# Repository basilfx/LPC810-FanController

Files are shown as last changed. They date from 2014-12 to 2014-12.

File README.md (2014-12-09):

# LPC810 Fan Controller
Tiny PID-based fan controller board and firmware, to insert between 3-pin fans.

## Contents
* Eagle schematic and PCB
* Firmware
* PID simulator and monitor

## Eagle

### Bill of Materials
The value of is a pullup resistor for the DS18B20 temperature sensor. While 4.7k is adviced, I use 470 in parasite mode. Higher values did not work for higher temperatures.

| Part | Value  | Device | Package |
|---|---|---|---|
| R1 | 470 | R-EU_R0603 | R0603 |
| R2 | 10k | R-EU_R0603 | R0603 |
| R3 | 10k | R-EU_R0603 | R0603 |
| R4 | 10k | R-EU_R0603 | R0603 |
| C1 | 100nF  | C-EUC0603 | C0603 |
| C2 | 2.2µF  | C-EUC0805 | C0805 |
| C3 | 100nF  | C-EUC0603 | C0603 |
| C4 | 2.2µF  | C-EUC0805 | C0805 |
| Q1 | BSH103 | MOSFET-NCHANNEL | SOT23 |
| U1 | LP2985 | LP2985-33DBVT | SOT95P  |
| U2 | LPC810 | LPC810M021FN8 | DIP8 |

### Board render
The board measures 0.45x0.95 inch. Below a render of the top and bottom.

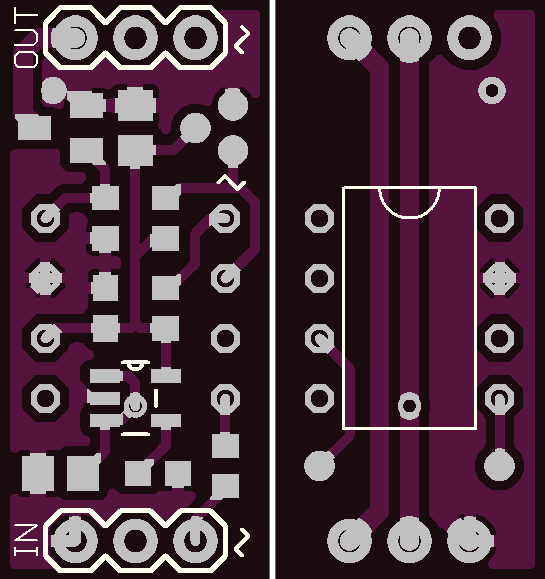
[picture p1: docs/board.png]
brd


## Firmware
The firmware can be found in the `firmware/` folder. It compiles fine with the [GCC ARM Embedded](https://launchpad.net/gcc-arm-embedded) toolchain. Just run `make`.

## Contrib
In the `contrib` folder contains some tools to test the PID controller. First, run `python setup.py build_ext --inplace` to build a Python wrapper for the exact same PID controller in the firmware. This requires Cython to be available.

## License
See the `LICENSE` file (MIT license).

This software makes use of other software. Please see `firmware/README.md` for more information.

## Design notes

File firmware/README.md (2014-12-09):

# Firmware

## Configuration
Configurable parameters can be defined in `inc/config.h`.

## Included libraries
This code makes use of the following libraries. Some are slightly modified.

* [LPCOpen](http://www.lpcware.com/content/nxpfile/lpcopen-platform) &mdash; `lib/lpcopen`
* [PID Controller](http://www.atmel.com/images/doc2558.pdf) (modified) &mdash; `lib/pid`
* [1-Wire](https://github.com/kbiva/lpc8xx_libs) (modified) &mdash; `lib/1-wire`
* [DS18x20](https://github.com/kbiva/lpc8xx_libs) (modified) &mdash; `lib/ds18x20`
* [Tiny printf](http://forum.43oh.com/topic/1289-tiny-printf-c-version/) &mdash; `lib/printf`

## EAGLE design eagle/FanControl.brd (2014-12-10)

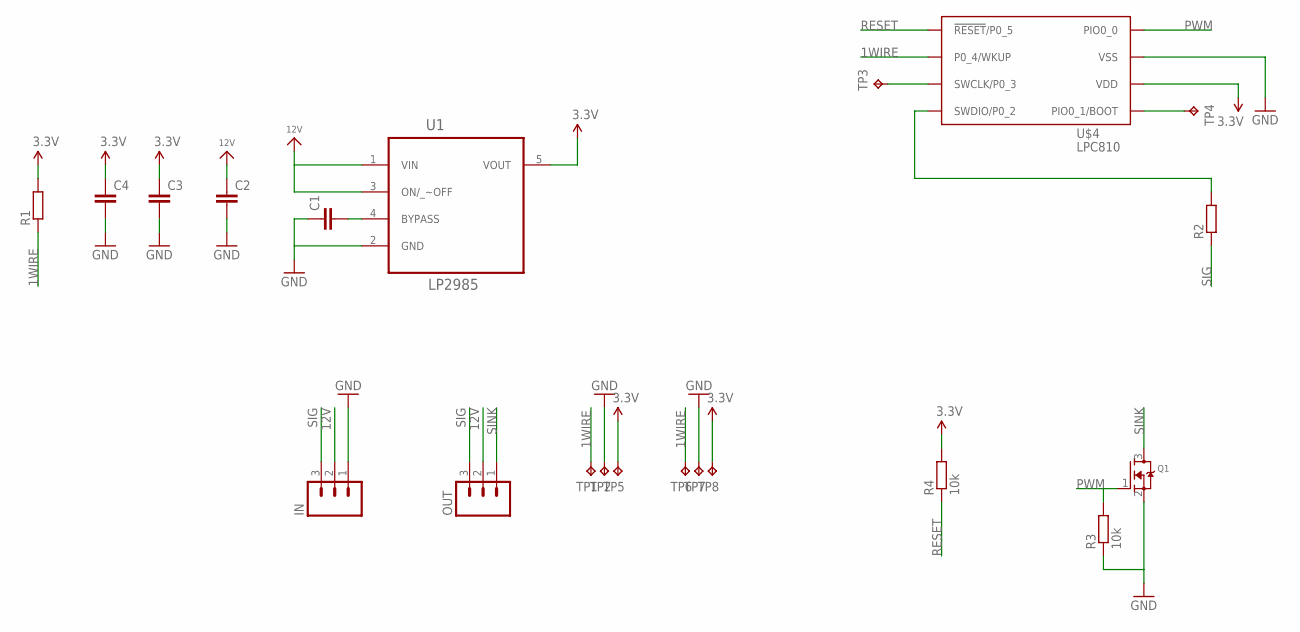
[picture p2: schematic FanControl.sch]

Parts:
C1, C3: C-EUC0603; C0603
C2, C4: C-EUC0805; C0805
IN: M03PTH; 1X03
OUT: M03PTH; 1X03
Q1: MOSFET-NREFLOW; SOT23
R1, R2: R-EU_R0603; R0603
R3, R4: 10k; R0603
TP1, TP2, TP3, TP4, TP5, TP6, TP7, TP8: TPB1,27; B1,27
U1: LP2985; SOT95P280X145-5N
U$4: LPC810; DIP8

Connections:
1WIRE: R1.1, TP1.TP, TP6.TP, U$4.P$2 (P0_4/WKUP)
3.3V: C3.1, C4.1, R1.2, R4.2, TP5.TP, TP8.TP, U1.5 (VOUT), U$4.P$6 (VDD)
12V: C2.1, IN.2, OUT.2, U1.1 (VIN), U1.3 (ON/_~OFF)
GND: C1.1, C2.2, C3.2, C4.2, IN.1, Q1.2 (S), R3.1, TP2.TP, TP7.TP, U1.2 (GND), U$4.P$7 (VSS)
unnamed: C1.2, U1.4 (BYPASS)
unnamed: R2.2, U$4.P$4 (SWDIO/P0_2)
unnamed: TP3.TP, U$4.P$3 (SWCLK/P0_3)
unnamed: TP4.TP, U$4.P$5 (PIO0_1/BOOT)
PWM: Q1.1 (G), R3.2, U$4.P$8 (PIO0_0)
RESET: R4.1, U$4.P$1 (!RESET!/P0_5)
SIG: IN.3, OUT.3, R2.1
SINK: OUT.1, Q1.3 (D)

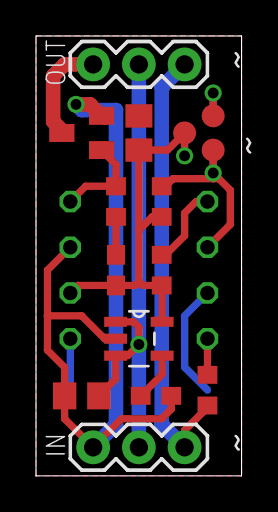
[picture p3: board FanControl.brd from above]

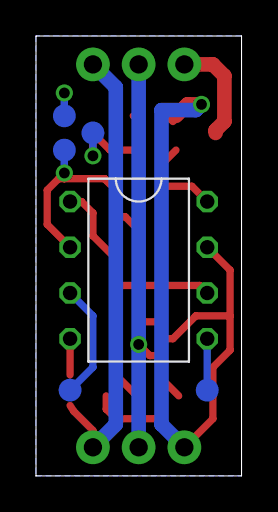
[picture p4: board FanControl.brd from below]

Board: 2 copper layers, 11.4 x 24.4 mm, 21 parts (6 on the bottom side), 12 nets.

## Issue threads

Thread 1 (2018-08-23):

plugin needed to handle lto object

yhyuan, 2018-08-23:
Hi
When I tried to compile with
arm-none-eabi-gcc (GNU Tools for Arm Embedded Processors 7-2018-q2-update) 7.3.1 20180622 (release) [ARM/embedded-7-branch revision 261907]
The following error is found
arm-none-eabi-ld: lib/lpcopen/src/uart_8xx.o: plugin needed to handle lto object
arm-none-eabi-ld: lib/lpcopen/src/wkt_8xx.o: plugin needed to handle lto object
arm-none-eabi-ld: lib/lpcopen/src/wwdt_8xx.o: plugin needed to handle lto object
arm-none-eabi-ld: lib/1-wire/src/1-Wire.o: plugin needed to handle lto object
arm-none-eabi-ld: lib/1-wire/src/1-WireCRC.o: plugin needed to handle lto object
arm-none-eabi-ld: lib/ds18x20/src/DS18x20.o: plugin needed to handle lto object
arm-none-eabi-ld: lib/pid/src/pid.o: plugin needed to handle lto object
arm-none-eabi-ld: lib/printf/src/printf.o: plugin needed to handle lto object

any clue?

basilfx, 2018-08-27:
This is probably related to your compiler version. You can see if your compiler is compiled with LTO support (see [here](https://www.reddit.com/r/Gentoo/comments/6b1dlc/plugin_needed_to_handle_lto_object_and_correct/)), or remove `-flto` from the command line (generates larger binary).

Closed 2018-08-29.

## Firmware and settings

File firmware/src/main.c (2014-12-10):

/*
 * @brief UART API in ROM (USART API ROM) interrupt example
 *
 * @note
 * Copyright(C) NXP Semiconductors, 2012
 * All rights reserved.
 *
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
 * @par
 * Permission to use, copy, modify, and distribute this software and its
 * documentation is hereby granted, under NXP Semiconductors' and its
 * licensor's relevant copyrights in the software, without fee, provided that it
 * is used in conjunction with NXP Semiconductors microcontrollers.  This
 * copyright, permission, and disclaimer notice must appear in all copies of
 * this code.
 */

#include <string.h>

#include "chip.h"
#include "1-Wire.h"
#include "DS18x20.h"
#include "pid.h"

#include "config.h"

/* UART handle and memory for ROM API */
static UART_HANDLE_T *uartHandle;

/* Use a buffer size larger than the expected return value of
   uart_get_mem_size() for the static UART handle type */
static uint32_t uartHandleMEM[0x10];

/* Saved tick count used for a PWM cycle */
volatile uint32_t cycleTicks;

/* Milliseconds tick */
volatile uint32_t ticks = 0;

/* Number of Mhz for us delay calculation */
volatile uint32_t mhz = 0;

/* DS1820 temperature sensors */
uint8_t sensorCount = 0;
uint8_t sensorIDs[ONE_WIRE_DEVICE_NUMBER_MAX][DS18x20_SERIAL_NUM_SIZE];

extern void printf(char *format, ...);

/**
 * Handle interrupt from State Configurable Timer
 */
void SCT_IRQHandler(void)
{
    Chip_SCT_ClearEventFlag(LPC_SCT, SCT_EVT_0);
}

/**
 * Increment number of milliseconds
 */
void SysTick_Handler(void)
{
    ticks++;
}

/**
 * Delay a certain amount of milliseconds. In the mean time, wait for
 * interrupts.
 */
void delay_ms(uint32_t count)
{
    uint32_t end = ticks + count;

    while (ticks < end) {
        __WFI();
    }
}

/**
 * Delay a certian amount of microseconds. In the mean time, stall the bus
 * (including interrupts).
 */
void delay_us(uint32_t count)
{
    Chip_MRT_SetInterval(LPC_MRT_CH1, (count * mhz - 3));
}

/**
 * Initialize delay_ms and delay_us.
 */
static void init_delays()
{
    /* Systick at 1ms interval */
    SysTick_Config(Chip_Clock_GetSystemClockRate() / 1000);

    /* MRT for us delay */
    Chip_MRT_Init();
    Chip_MRT_SetMode(LPC_MRT_CH1, MRT_MODE_ONESHOT_BUS_STALL);
    mhz = Chip_Clock_GetSystemClockRate() / 1000000;
}

/**
 * UART Pin mux function - note that SystemInit() may already setup your pin
 * muxing at system startup
 */
static void init_pinmux(void)
{
    /* Enable the clock to the Switch Matrix */
    Chip_SWM_Init();

    Chip_Clock_SetUARTClockDiv(1);  /* divided by 1 */

    /* Setup UART output */
    Chip_SWM_MovablePinAssign(SWM_U0_TXD_O, 1); //PIO0_1

    /* Setup 1-Wire input */
    Chip_SWM_DisableFixedPin(SWM_FIXED_SWCLK); //PIO0_3

    /* Setup PWM */
    Chip_SWM_MovablePinAssign(SWM_CTOUT_0_O, 0);

    /* Setup tach */
    Chip_SWM_DisableFixedPin(SWM_FIXED_SWDIO);

    /* Disable the clock to the Switch Matrix to save power */
    Chip_SWM_Deinit();
}

/**
 * Setup UART handle and parameterss
 */
static void init_uart()
{
    uint32_t multiplier;

    /* Initialize UART */
    Chip_UART_Init(LPC_USART0);

    /* 115.2KBPS, 8N1, ASYNC mode, no errors, clock filled in later */
    UART_CONFIG_T cfg = {
        0,        /* U_PCLK frequency in Hz */
        115200,   /* Baud Rate in Hz */
        1,        /* 8N1 */
        0,        /* Asynchronous Mode */
        NO_ERR_EN /* Enable No Errors */
    };

    /* Perform a sanity check on the storage allocation */
    if (LPC_UART_API->uart_get_mem_size() > sizeof(uartHandleMEM)) {
        while(1) {};
    }

    /* Setup the UART handle */
    uartHandle = LPC_UART_API->uart_setup((uint32_t) LPC_USART0, (uint8_t *) &uartHandleMEM);

    if (uartHandle == NULL) {
        while(1) {};
    }

    /* Need to tell UART ROM API function the current UART peripheral clock speed */
    cfg.sys_clk_in_hz = Chip_Clock_GetSystemClockRate();

    /* Initialize the UART with the configuration parameters */
    multiplier = LPC_UART_API->uart_init(uartHandle, &cfg);

    if (multiplier) {
        Chip_SYSCTL_SetUSARTFRGDivider(0xFF); /* always 0xFF*/
        Chip_SYSCTL_SetUSARTFRGMultiplier(multiplier);
    }
}

/**
 * Initialize the PWM mode of the SCT.
 */
static void init_pwm()
{
    Chip_SCT_Init(LPC_SCT);

    /* Configure the SCT as a 32bit counter using the bus clock */
    LPC_SCT->CONFIG = SCT_CONFIG_32BIT_COUNTER | SCT_CONFIG_CLKMODE_BUSCLK;

    /* Initial CTOUT0 state is high */
    LPC_SCT->OUTPUT = (7 << 0);

    /* The PWM will use a cycle time of (PWM_FREQUENCY)Hz based off the bus clock */
    cycleTicks = Chip_Clock_GetSystemClockRate() / PWM_FREQUENCY;

    /* Setup for match mode */
    LPC_SCT->REGMODE_L = 0;

    /* Setup match counter 0 for the number of ticks in a PWM sweep, event 0
        will be used with the match 0 count to reset the counter.  */
    LPC_SCT->MATCH[0].U = cycleTicks;
    LPC_SCT->MATCHREL[0].U = cycleTicks;
    LPC_SCT->EVENT[0].CTRL = 0x00001000;
    LPC_SCT->EVENT[0].STATE = 0xFFFFFFFF;
    LPC_SCT->LIMIT_L = (1 << 0);

    /* For CTOUT0 to CTOUT2, event 1 is used to clear the output */
    LPC_SCT->OUT[0].CLR = (1 << 0);
    LPC_SCT->OUT[1].CLR = (1 << 0);
    LPC_SCT->OUT[2].CLR = (1 << 0);

    /* Setup event 1 to trigger on match 1 and set CTOUT0 high */
    LPC_SCT->EVENT[1].CTRL = (1 << 0) | (1 << 12);
    LPC_SCT->EVENT[1].STATE = 1;
    LPC_SCT->OUT[0].SET = (1 << 1);

    /* Don't use states */
    LPC_SCT->STATE_L = 0;

    /* Unhalt the counter to start */
    LPC_SCT->CTRL_U &= ~(1 << 2);
}

/**
 * Set the PWM value. Value is a percentage between 0-100.
 */
void set_pwm(uint8_t percentage)
{
    uint32_t value, newTicks;;

    if (percentage >= 100) {
        value = 100;
    }
    else if (percentage == 0) {
        value = cycleTicks + 1;
    }
    else {
        newTicks = (cycleTicks * percentage) / 100;

        /* Approximate duty cycle rate */
        value = cycleTicks - newTicks;
    }

    LPC_SCT->MATCHREL[1].U = value;
}

/**
 * Send a single character on the UART using polling mode.
 */
void put_char(char c)
{
    LPC_UART_API->uart_put_char(uartHandle, c);
}

/**
 * Send a string on the UART terminated by a NULL character using polling mode.
 */
void put_string(char* s)
{
    UART_PARAM_T param;

    param.buffer = (uint8_t *) s;
    param.size = strlen(s);

    /* Polling mode, do not append CR/LF to sent data */
    param.transfer_mode = TX_MODE_SZERO;
    param.driver_mode = DRIVER_MODE_POLLING;

    /* Transmit the data */
    if (LPC_UART_API->uart_put_line(uartHandle, &param)) {
        while(1) {};
    }
}

/**
 * Main Function
 */
int main(void)
{
    uint8_t i;
    uint8_t state = 0;

    int32_t temperature[NUMBER_OF_SENSORS];
    pid_data_t pid[NUMBER_OF_SENSORS];

    /* Initialize delays */
    init_delays();

    /* Initialize pins */
    init_pinmux();

    /* Initialize peripherals */
    init_uart();
    init_pwm();

    /* Main loop for application. */
    while (1) {
        if (state == 0) {
            /* Reset 1-Wire bus */
            uint8_t attempts = 10;

            while (attempts-- && One_Wire_Reset()) {
                delay_ms(100);
            }

            /* Find connected sensors */
            DS18x20_Search_Rom(&sensorCount, &sensorIDs);

            /* Check for temperature sensors, otherwise go into error mode */
            printf("Found %i/%i sensors\r\n", (int16_t) sensorCount, NUMBER_OF_SENSORS);

            if (sensorCount != NUMBER_OF_SENSORS) {
                state = 128;
            } else {
                state = 1;
            }
        } else if (state == 1) {
            /* Setup PID controllers */
            for (i = 0; i < NUMBER_OF_SENSORS; i++) {
                PID_Controller_Init(&pid[i], PID_SETTINGS[i][0], PID_SETTINGS[i][1], PID_SETTINGS[i][2]);
            }

            state = 2;
        } else if (state == 2) {
            /* Start reading temperature by all sensors */
            DS18x20_Start_Conversion_Skip_Rom();

            /* Wait for conversion to complete. */
            delay_ms(1000);

            /* Fetch results individually */
            uint8_t success = 1;

            for (i = 0; i < NUMBER_OF_SENSORS; i++) {
                uint8_t result = DS18x20_Get_Conversion_Result_by_ROM_CRC(&sensorIDs[i], &temperature[i]);

                /* Advance to output state */
                if (result == ONE_WIRE_SUCCESS) {
                    if ((temperature[i] / 100) > 1000) {
                        printf("Temperature of sensor %i invalid: %n\r\n", (int16_t) i, temperature);
                        success = 0;
                    }
                } else {
                    printf("Reading of sensor %i failed: %i\r\n", (int16_t) i, (int16_t) result);
                    success = 0;
                }
            }

            /* Advance only on success */
            if (success) {
                state = 3;
            }
        } else if (state == 3) {
            /* Update PID controllers */
            uint8_t speed[NUMBER_OF_SENSORS], maxSpeed = 0;

            for (i = 0; i < NUMBER_OF_SENSORS; i++) {
                int16_t out = -1 * PID_Controller_Update(&pid[i], temperature[i] / 100, TEMPERATURE_SETTINGS[i]);

                /* Set new speed. */
                if (out > 0) {
                    speed[i] = ((int32_t) out) * 100 / SCALING_FACTOR;

                    /* Some fans don't run below a certain speed */
                    if (speed[i] < MINIMAL_FAN_SPEED) {
                        speed[i] = 0;
                    }
                } else {
                    speed[i] = 0;
                }

                /* Take max speed */
                if (speed[i] > maxSpeed) {
                    maxSpeed = speed[i];
                }

                /* Debugging */
                printf("%i,%n,%n,%u,%i,", i, temperature[i] / 100, TEMPERATURE_SETTINGS[i], (uint16_t) speed[i], out);
            }

            /* Debugging */
            printf("%u\r\n", (uint16_t) maxSpeed);

            /* Set new speed */
            set_pwm(maxSpeed);

            /* Advance to measurement state */
            state = 2;
        } else if (state == 128) {
            /* Infinitely spin fan up and down to tell something is wrong. */
            set_pwm(100);
            delay_ms(5000);
            set_pwm(0);
            delay_ms(5000);
        }
    }

    /* Should not end here */
    return 0;
}

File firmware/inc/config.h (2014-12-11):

#ifndef __CONIFG_H__
#define __CONFIG_H__

/* PWM frequency (Hz). Higher values produce less PWM noise. */
#define PWM_FREQUENCY (50000)

/* Minimal fan speed (%) */
#define MINIMAL_FAN_SPEED (10)

/* Number of temperature sensors */
#define NUMBER_OF_SENSORS (2)

/* Target temperature per sensor (C * 10) */
const int32_t TEMPERATURE_SETTINGS[NUMBER_OF_SENSORS] = { 350, 450 };

/* PID settings per sensor (Kp, Ki, Kd) */
const int16_t PID_SETTINGS[NUMBER_OF_SENSORS][3] = { PID_VALUES(2, 0.1, 0.5), PID_VALUES(4, 0.03125, 0.5) };

#endif

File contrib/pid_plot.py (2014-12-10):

import argparse
import time
import sys

import matplotlib.pyplot as plot

def main():
    """
    Monitor stdin for incoming data and parse it. When the stream closes, the
    graph will be plotted.

    Format of data: i,temperature_i,target_i,speed_i,pid_i,...,max_speed
    """

    # Gather data
    start = time.time()
    sensors = None
    data = []

    try:
        while True:
            # Read data
            line = sys.stdin.readline()

            if not line:
                break

            # Split data
            line = line.strip().split(",")

            # Determine number of sensors from first line of data
            if (len(line) - 2) % 5 == 0:
                if sensors is None:
                    sensors = (len(line) - 2) / 5
            else:
                continue

            # Check if all data is available
            if len(line) != sensors * 5 + 2:
                continue

            # Parse the data
            data.append(map(int, line))
    except KeyboardInterrupt:
        pass

    # Check for data
    if not data:
        return

    # Generate graph
    figure = plot.figure()
    axis = None

    times = zip(*data)[0]
    max_speeds = zip(*data)[-1]

    for i in xrange(sensors):
        _, temperatures, targets, speeds, pids = zip(*data)[i*5 + 1:i*5 + 6]

        axis = figure.add_subplot(1, sensors, i + 1, sharey=axis)
        axis2 = axis.twinx()

        axis.plot(times, targets, color="b", label="Target")
        axis.plot(times, temperatures, color="c", label="Temperature")
        #axis2.plot(times, pids, color="m", label="PID Out")
        axis2.plot(times, speeds, color="y", label="Speed")
        axis2.plot(times, max_speeds, color="r", label="Max Speed")

        axis.set_xlabel("Time (s)")
        axis.set_ylabel("Temperature (C)")
        axis2.set_ylabel("Control (%)")

        axis.set_ylim(bottom=0, top=1000)
        axis2.set_ylim(bottom=0, top=100)

        axis.grid()

    # Show
    plot.show()

if __name__ == "__main__":
    sys.exit(main())

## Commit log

2014-12-08 Second version of schematics and PCB
    [FanControl.brd, FanControl.sch]
2014-12-09 Lower temperature.
2014-12-09 Updated README with a BOM.
2014-12-09 Increase stack size for printf magic.
2014-12-09 Add support for multiple sensors controlling one fan.
2014-12-09 Monitor multiple sensors.
2014-12-10 Added extra pads for another 1-Wire device on the bottom layer.
    [FanControl.brd, FanControl.sch]
2014-12-10 Reimplemented PID controller to account for better value ranges.

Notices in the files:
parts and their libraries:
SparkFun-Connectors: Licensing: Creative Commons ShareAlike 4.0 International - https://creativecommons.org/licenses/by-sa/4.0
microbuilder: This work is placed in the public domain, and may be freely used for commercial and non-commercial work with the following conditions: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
